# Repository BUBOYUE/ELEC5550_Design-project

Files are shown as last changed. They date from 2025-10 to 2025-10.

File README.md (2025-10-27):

## Version Information

- **Version:** 3.1 (Final Release)
- **Date:** 2025-10-27
- **Editor:** Boyue BU
- **Description:**
  - Fixed unstable recognition issues for different mouse types.
  - Added support for recognizing different signaling variants of mouse/keyboard (Report/Boot protocol, Report ID handling).
  - Mouse, keyboard, and U‑Disk functionalities are now complete.
  - Adjusted documentation to reflect the new HID compatibility improvements.
  - Completed the final version of the project (software, hardware, and documentation updated).
  - Added compatibility note for **ESP32-S3 DevKitC V1**, allowing firmware testing without the custom PCB.
  - Improved **Host/Device** dual communication protocol and FEC verification mechanism.
  - Updated **README.md** with library linking instructions and board compatibility notes.
  - Added **BSD 3-Clause License** for attribution-based redistribution.
  - Expanded **References** section with official ESP-IDF and TinyUSB sources.
  - Adjusted folder structure for correct GitHub rendering.
  - Enhanced TinyUSB HID/MSC framework and debugging interfaces.

# ELEC5550 Design Project – Laser-Based USB Communication System

This repository contains the complete design files for the **ELEC5550 Design Project** at the **University of Western Australia (UWA)**.  
The goal of this project is to develop a **dual ESP32-S3 optical communication bridge** that enables transparent data transfer between a **PC** and **USB devices** (keyboard, mouse, or mass storage) through a **laser-based optical link**.

---

## 📁 Project Structure

```
ELEC5550_Design-project/
│
├── docs/                         # datasheets,figures
│
├── hardware/                     # Hardware design files
│   ├── schematics/               # Circuit schematics (KiCad / Altium)
│   ├── pcb/                      # PCB layout and Gerber files
│   └── sim/                      # Simulation on LTspice
│
├── software/                     # Firmware source code for ESP32-S3 boards
│   ├── esp32_a_host/             # Host-side firmware (USB Host + UART TX)
│   ├── esp32_b_device/           # Device-side firmware (UART RX + USB Device)
│   ├── esp32s3_usb_passthrough/  # Combined HID + MSC passthrough final demo
│   └── libraries/                # Local Arduino libraries (CRC, UART, FEC, etc.)
│
├── tools/                        # Utility scripts or helper tools
│
└── README.md 
```

---

## 🧩 Hardware Compatibility

This project is designed for the **ESP32-S3 WROOM N16R8** module used on the custom PCB.  
If you do not have access to the fabricated PCB, the firmware can still be tested using an **ESP32-S3 DevKitC V1** board.  
Simply connect the UART interface between two boards according to the schematic, and the program will run with equivalent functionality.

---

## ⚙️ Setup Guide

### 1. Clone the Repository
```bash
git clone https://github.com/BUBOYUE/ELEC5550_Design-project.git
```

### 2. Link the Local Libraries
To ensure the Arduino IDE can locate the custom libraries used in this project, create symbolic links from the project’s `libraries` folder to your Arduino library path.

**Mac/Linux:**
```bash
ln -s <path_to_project>/software/libraries ~/Documents/Arduino/libraries/ELEC5550_LIBS
```

**Windows (PowerShell):**
```powershell
New-Item -ItemType SymbolicLink -Path "$env:USERPROFILE\Documents\Arduino\libraries\ELEC5550_LIBS" -Target "<path_to_project>\software\libraries"
```

### 3. Open and Flash
1. Open `esp32_a_host.ino` or `esp32_b_device.ino` using Arduino IDE.  
2. Select **Board:** `ESP32S3 Dev Module`.  
3. Set **Upload Speed:** `460800`.  
4. Enable **USB CDC On Boot** if available.  
5. Connect the board and upload.

---

## 💡 Project Overview

- **Architecture:** Dual ESP32-S3 optical bridge  
- **Communication Link:** UART or laser-based optical channel  
- **Supported Protocols:** HID (mouse/keyboard) + MSC (USB mass storage)  
- **Error Handling:** CRC-16 + Reed–Solomon FEC  
- **Operating Voltage:** 5V / 1A (from PC or power bank)

The host board (ESP32-A) acts as a USB Host, while the device board (ESP32-B) emulates a USB peripheral, enabling transparent USB data transmission over light.

---

## 🧠 Contributors
- **Boyue BU** – Software (Host-side, USB HID/MSC RTOS structure)
- **Elyney OU** – Software (Device-side, TinyUSB HID/MSC logic)
- **Kunze CHEN** – Software (UART Communication Protocol, Error Correction)
- **Zhanjun XU** – Hardware (Laser Driver Design & PCB design)
- **Zhe WANG** – Hardware (Receiver Design & PCB design)
- **Bowen LIU** – Hardware (Receiver Design & PCB design)

---

## 🧩 References
- [ESP-IDF TinyUSB Examples](https://github.com/espressif/esp-idf/tree/master/examples/peripherals/usb)
- [Arduino-ESP32 USBMSC Example](https://github.com/espressif/arduino-esp32/blob/master/libraries/USB/examples/USBMSC/USBMSC.ino)
- [TinyUSB Library](https://github.com/hathach/tinyusb)
- [Reed–Solomon C++ Implementation (mersinvald)](https://github.com/mersinvald/Reed-Solomon/blob/master/include/rs.hpp)
- [CRC Algorithms Reference (Boost.CRC library, C++)](https://www.boost.org/doc/libs/release/libs/crc/crc.html)
- [ESP-IDF USB Host HID Example](https://github.com/espressif/esp-idf/tree/master/examples/peripherals/usb/host/hid)
- [ESP-IDF USB Host MSC Example](https://github.com/espressif/esp-idf/tree/master/examples/peripherals/usb/host/msc)
- [HID Report Parser](https://github.com/pasztorpisti/hid-report-parser)
---

## 📜 License
This project is licensed under the [BSD 3-Clause License](./LICENSE).  
© 2025 ELEC5550 Optical Communication Team, University of Western Australia.  
Redistribution is permitted with acknowledgment of the original authors.

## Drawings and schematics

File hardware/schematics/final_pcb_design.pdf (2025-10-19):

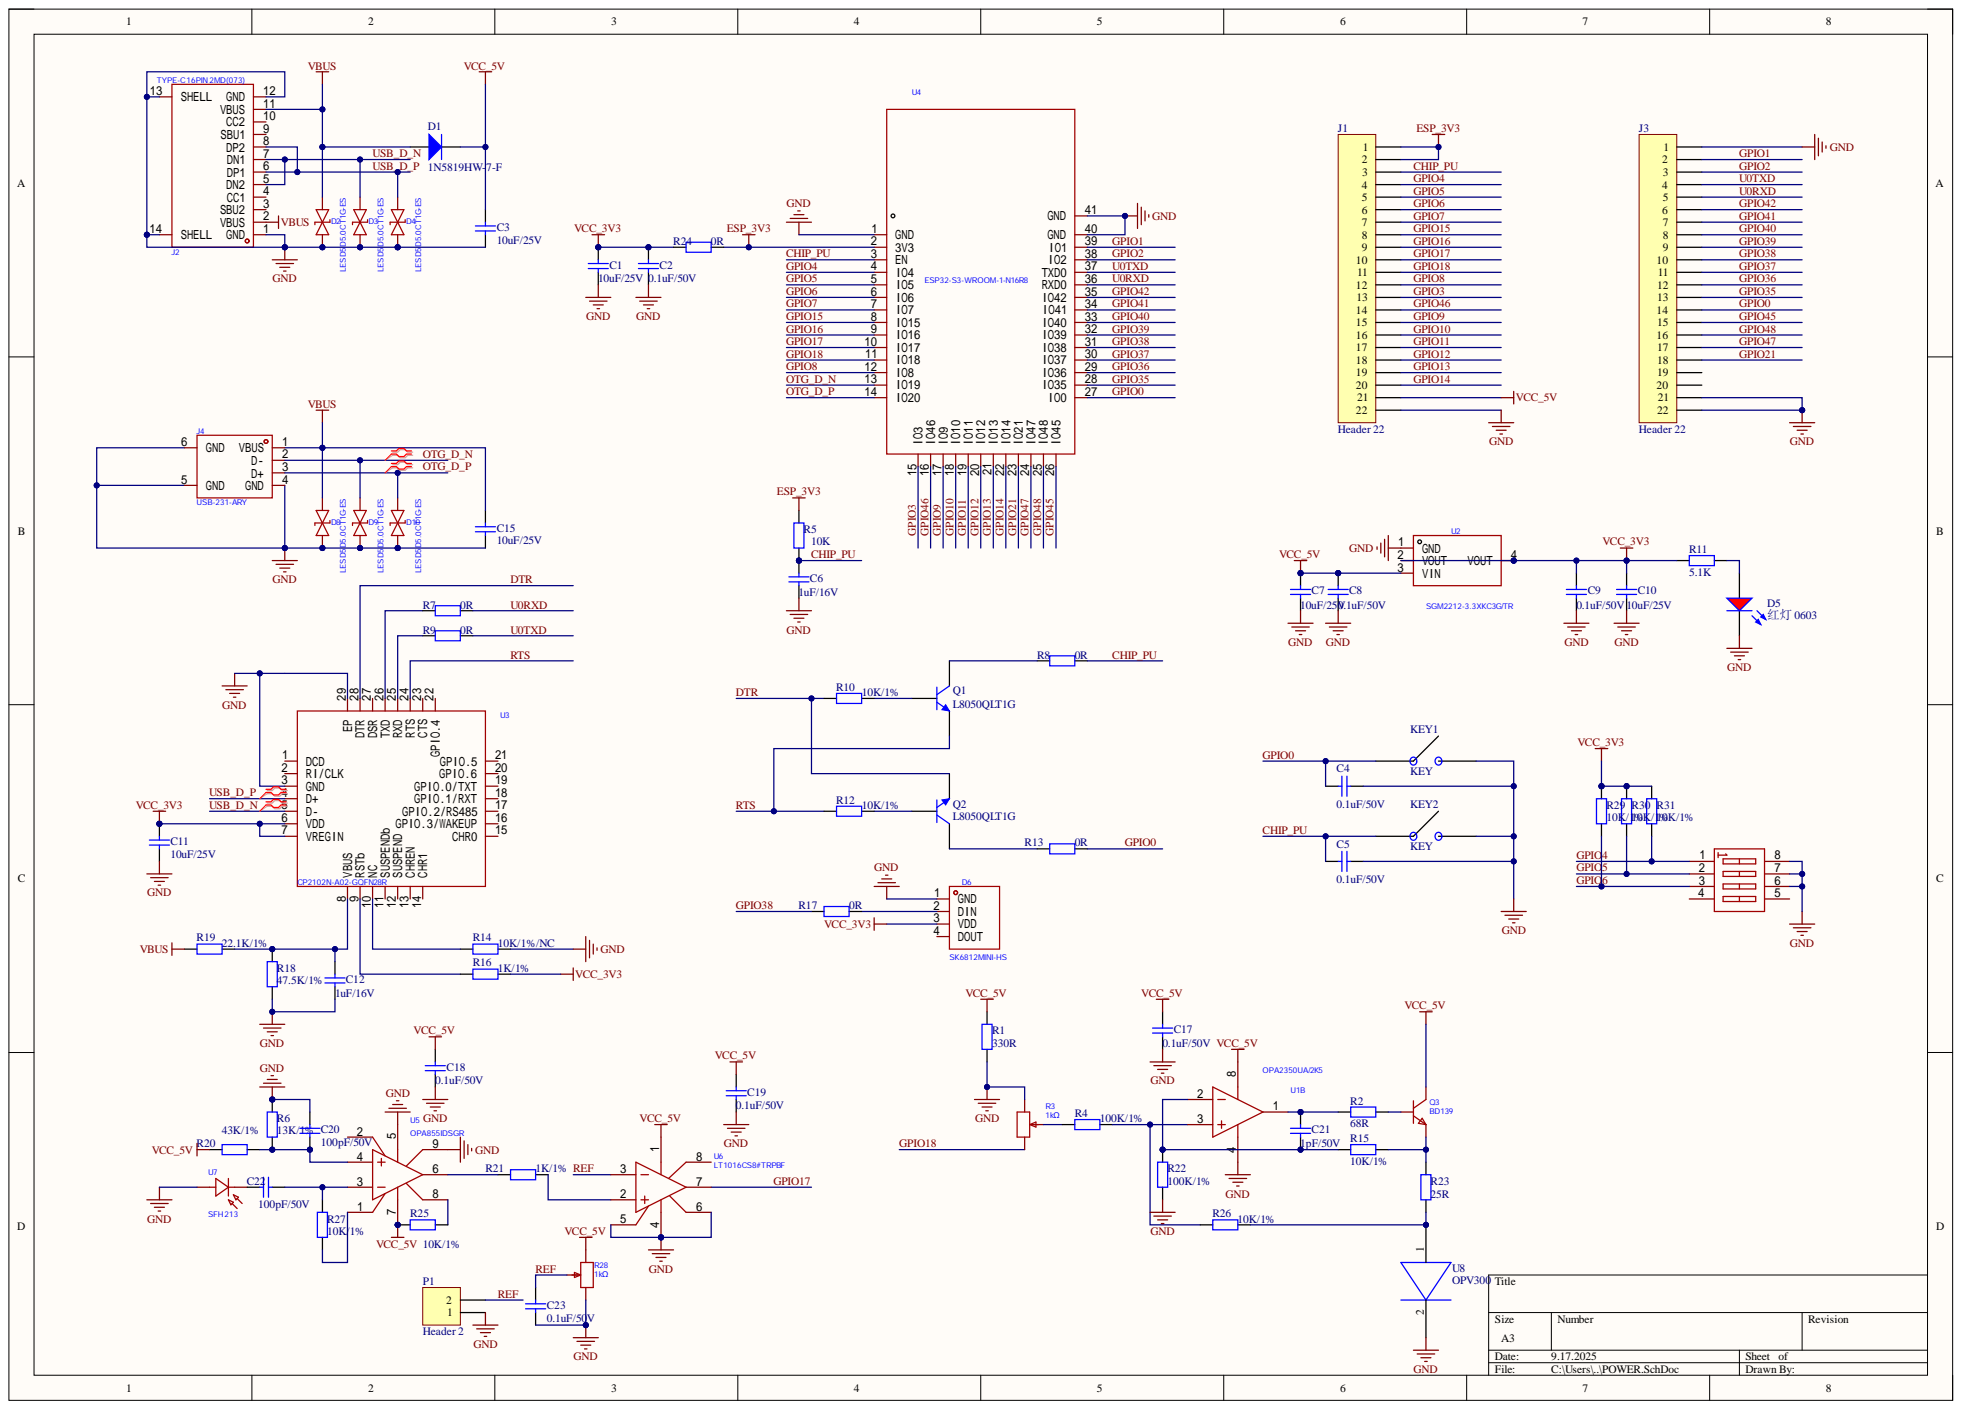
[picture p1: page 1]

OTG_D_N
OTG_D_P

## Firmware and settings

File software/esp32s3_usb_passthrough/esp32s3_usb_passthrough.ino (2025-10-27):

/*
 * Project: ELEC5550 Laser USB Passthrough (ESP32‑S3)
 * File:    esp32s3_usb_passthrough.ino
 * Authors : UWA ELEC5550 Team 13 (merged by Boyue BU)
 * Date:    2025-10-15
 * 
 * Summary:
 *   Unified sketch that lets one ESP32‑S3 board act as a USB Host (HID + MSC)
 *   and transparently bridge traffic to a peer ESP32‑S3 over UART using a
 *   framed protocol with CRC and optional FEC (Reed–Solomon). The peer may act
 *   as a USB Device endpoint (HID/MSC). Mode selection is done via GPIO5.
 *
 * Context:
 *   University of Western Australia (UWA) – ELEC5550 Design Project, Group 13.
 *   This file consolidates the previously separate HID and MSC passthrough
 *   sketches and adds UART framing, task scheduling, and logging for a laser
 *   data link.
 *
 * Key Features:
 *   - TinyUSB Host: HID (keyboard/mouse) + MSC (U‑Disk) handling on S3‑A
 *   - UART framing: Type/Len/Payload + CRC, optional RS FEC (payload ≤ 224 B)
 *   - FreeRTOS tasks: USB events, MSC app queue, UART RX/TX, HID callbacks
 *   - Zero‑block optimization for MSC reads (U_EMPTY), write acknowledgement
 *   - Dual‑mode: Host/Device decided by GPIO5 (HIGH=Host, LOW=Device)
 *
 * Build/Run Notes:
 *   - Platform: Arduino‑ESP32 for ESP32‑S3
 *   - Serial monitor: 460800 bps (logging and diagnostics)
 *   - Power/role: Set board role with the on‑board switch tied to GPIO5
 *
 * References:
 *   - ESP‑IDF examples: HID Host (hid_host) and MSC Host (msc_host)
 *   - TinyUSB stack and ESP32‑S3 USB Host driver
 *
 * Disclaimer:
 *   Educational code produced by UWA student team; provided "as is" without any
 *   warranty. Review licensing before redistribution.
 */


#include <Arduino.h>
#include <stdio.h>
#include <string.h>
#include <wchar.h>
#include <inttypes.h>
#include <sys/stat.h>
#include <dirent.h>
#include <errno.h>

#include "freertos/FreeRTOS.h"
#include "freertos/task.h"
#include "freertos/queue.h"

#include "esp_err.h"
#include "esp_log.h"
#include "esp_timer.h"

#include "driver/gpio.h"
#include "usb/usb_host.h"

#include "hid_host.h"
#include "hid_usage_keyboard.h"
#include "hid_usage_mouse.h"

#include "msc_host.h"
#include "msc_host_vfs.h"

#include "uart.h"   // Provides: uart2_init(), send_frame(...)
#include "usb.h"    // Optional: for future USB HID device forwarding

#include "device.h" // Declares device_usb_init / device_mouse_and_keyboard / Close_Ustick etc.

#include "hid_report_parser.h"

/**
 * @brief HID Protocol string names
 */
static const char *hid_proto_name_str[] = {"NONE", "KEYBOARD", "MOUSE"};

/**
 * @brief Key event
 */
typedef struct {
  enum key_state { KEY_STATE_PRESSED = 0x00, KEY_STATE_RELEASED = 0x01 } state;
  uint8_t modifier;
  uint8_t key_code;
} key_event_t;

typedef struct {
  hid::SelectiveInputReportParser parser;
  hid::MouseConfig cfg;
  hid::BoolVector buttons;
  hid::Int32Vector axes;
  bool inited;
} mouse_parser_ctx_t;

static mouse_parser_ctx_t g_mouse_ctx = {};

static void mouse_parser_reset(void) {
  g_mouse_ctx.parser.Reset();
  g_mouse_ctx.inited = false;
}

static void mouse_parser_init(hid_host_device_handle_t hid_device_handle) {
  size_t desc_len = 0;
  uint8_t* desc_ptr = hid_host_get_report_descriptor(hid_device_handle, &desc_len);
  if (!desc_ptr || desc_len == 0) {
    Serial.printf("[HID][Mouse] get report descriptor failed (len=%u)\n", (unsigned)desc_len);
    mouse_parser_reset();
    return;
  }

  hid::Collection* root = g_mouse_ctx.cfg.Init(&g_mouse_ctx.buttons, &g_mouse_ctx.axes, false);
  int r = g_mouse_ctx.parser.Init(root, (const void*)desc_ptr, desc_len);
  if (r != hid::ERR_SUCCESS) {
    root = g_mouse_ctx.cfg.Init(&g_mouse_ctx.buttons, &g_mouse_ctx.axes, true);
    r = g_mouse_ctx.parser.Init(root, (const void*)desc_ptr, desc_len);
  }

  if (r == hid::ERR_SUCCESS) {
    g_mouse_ctx.inited = true;
    Serial.printf("[HID][Mouse] parser ready (desc_len=%u)\n", (unsigned)desc_len);
  } else {
    Serial.printf("[HID][Mouse] parser init failed: %s (%d)\n", hid::str_error(r, "ERR"), r);
    mouse_parser_reset();
  }
}


static const char *TAG = "example";

#ifndef MNT_PATH
#define MNT_PATH "/usb"
#endif
#ifndef BUFFER_SIZE
#define BUFFER_SIZE (4 * 1024)
#endif
#ifndef APP_QUIT_PIN
#define APP_QUIT_PIN GPIO_NUM_0
#endif
// IMPORTANT NOTE
// MSC Class Driver is not fully support connecting devices through external Hub.
// TODO: Remove this line after MSC Class Driver will support it
static bool dev_present = false;

static uint32_t g_sector_size = 512;                 // Updated from device info
static msc_host_device_handle_t g_msc_dev = NULL;    // Current MSC device handle
static const uint8_t CHUNK_DATA_MAX = 224;           // Max data length per frame chunk (changed from 240 to 224)

/**
 * @brief Application Queue and its messages ID
 */
static QueueHandle_t app_queue;

typedef enum {
    APP_QUIT = 0,             // Explicitly define values
    APP_DEVICE_CONNECTED,
    APP_DEVICE_DISCONNECTED,
    APP_COMMAND,
} app_event_id_t;

typedef struct {
    app_event_id_t id;
    union {
        uint8_t new_dev_address;
        struct {                   // For UART command forwarding
            uint8_t type;          // Frame type (MsgType)
            uint8_t data[256];     // Payload
            uint8_t len;           // Payload length
        } cmd;
    } data;
} app_message_t;

// PC sends "raw type + raw payload" to this board via UART:
//   - Mouse:  TYPE = 0x01, followed by 3 bytes [dx, dy, btn]
//   - Keyboard: TYPE = 0x02, followed by 8 bytes [modifier, key1..key6, reserved]
// This board packs this raw payload using send_frame(type, payload, len) (adds STX/CRC) and sends downstream.

/*
 * SPDX-FileCopyrightText: 2022-2023 Espressif Systems (Shanghai) CO LTD
 *
 * SPDX-License-Identifier: Unlicense OR CC0-1.0
 */

/* GPIO Pin number for quit from example logic */
#define APP_QUIT_PIN                GPIO_NUM_0

QueueHandle_t hid_host_event_queue;
bool user_shutdown = false;

/**
 * @brief HID Host event
 *
 * This event is used for delivering the HID Host event from callback to a task.
 */
typedef struct {
  hid_host_device_handle_t hid_device_handle;
  hid_host_driver_event_t event;
  void *arg;
} hid_host_event_queue_t;


/* Main char symbol for ENTER key */
#define KEYBOARD_ENTER_MAIN_CHAR '\r'
/* When set to 1 pressing ENTER will be extending with LineFeed during serial
 * debug output */
#define KEYBOARD_ENTER_LF_EXTEND 1

/**
 * @brief Scancode to ascii table
 */
const uint8_t keycode2ascii[57][2] = {
    {0, 0},     /* HID_KEY_NO_PRESS        */
    {0, 0},     /* HID_KEY_ROLLOVER        */
    {0, 0},     /* HID_KEY_POST_FAIL       */
    {0, 0},     /* HID_KEY_ERROR_UNDEFINED */
    {'a', 'A'}, /* HID_KEY_A               */
    {'b', 'B'}, /* HID_KEY_B               */
    {'c', 'C'}, /* HID_KEY_C               */
    {'d', 'D'}, /* HID_KEY_D               */
    {'e', 'E'}, /* HID_KEY_E               */
    {'f', 'F'}, /* HID_KEY_F               */
    {'g', 'G'}, /* HID_KEY_G               */
    {'h', 'H'}, /* HID_KEY_H               */
    {'i', 'I'}, /* HID_KEY_I               */
    {'j', 'J'}, /* HID_KEY_J               */
    {'k', 'K'}, /* HID_KEY_K               */
    {'l', 'L'}, /* HID_KEY_L               */
    {'m', 'M'}, /* HID_KEY_M               */
    {'n', 'N'}, /* HID_KEY_N               */
    {'o', 'O'}, /* HID_KEY_O               */
    {'p', 'P'}, /* HID_KEY_P               */
    {'q', 'Q'}, /* HID_KEY_Q               */
    {'r', 'R'}, /* HID_KEY_R               */
    {'s', 'S'}, /* HID_KEY_S               */
    {'t', 'T'}, /* HID_KEY_T               */
    {'u', 'U'}, /* HID_KEY_U               */
    {'v', 'V'}, /* HID_KEY_V               */
    {'w', 'W'}, /* HID_KEY_W               */
    {'x', 'X'}, /* HID_KEY_X               */
    {'y', 'Y'}, /* HID_KEY_Y               */
    {'z', 'Z'}, /* HID_KEY_Z               */
    {'1', '!'}, /* HID_KEY_1               */
    {'2', '@'}, /* HID_KEY_2               */
    {'3', '#'}, /* HID_KEY_3               */
    {'4', '$'}, /* HID_KEY_4               */
    {'5', '%'}, /* HID_KEY_5               */
    {'6', '^'}, /* HID_KEY_6               */
    {'7', '&'}, /* HID_KEY_7               */
    {'8', '*'}, /* HID_KEY_8               */
    {'9', '('}, /* HID_KEY_9               */
    {'0', ')'}, /* HID_KEY_0               */
    {KEYBOARD_ENTER_MAIN_CHAR, KEYBOARD_ENTER_MAIN_CHAR}, /* HID_KEY_ENTER */
    {0, 0},      /* HID_KEY_ESC             */
    {'\b', 0},   /* HID_KEY_DEL             */
    {0, 0},      /* HID_KEY_TAB             */
    {' ', ' '},  /* HID_KEY_SPACE           */
    {'-', '_'},  /* HID_KEY_MINUS           */
    {'=', '+'},  /* HID_KEY_EQUAL           */
    {'[', '{'},  /* HID_KEY_OPEN_BRACKET    */
    {']', '}'},  /* HID_KEY_CLOSE_BRACKET   */
    {'\\', '|'}, /* HID_KEY_BACK_SLASH      */
    {'\\', '|'},
    /* HID_KEY_SHARP           */ // HOTFIX: for NonUS Keyboards repeat
                                  // HID_KEY_BACK_SLASH
    {';', ':'},                   /* HID_KEY_COLON           */
    {'\'', '"'},                  /* HID_KEY_QUOTE           */
    {'`', '~'},                   /* HID_KEY_TILDE           */
    {',', '<'},                   /* HID_KEY_LESS            */
    {'.', '>'},                   /* HID_KEY_GREATER         */
    {'/', '?'}                    /* HID_KEY_SLASH           */
};

/**
 * @brief Makes new line depending on report output protocol type
 *
 * @param[in] proto Current protocol to output
 */
static void hid_print_new_device_report_header(hid_protocol_t proto) {
  static hid_protocol_t prev_proto_output = HID_PROTOCOL_MAX;

  if (prev_proto_output != proto) {
    prev_proto_output = proto;
    printf("\r\n");
    if (proto == HID_PROTOCOL_MOUSE) {
      printf("Mouse\r\n");
    } else if (proto == HID_PROTOCOL_KEYBOARD) {
      printf("Keyboard\r\n");
    } else {
      printf("Generic\r\n");
    }
    fflush(stdout);
  }
}

/**
 * @brief HID Keyboard modifier verification for capitalization application
 * (right or left shift)
 *
 * @param[in] modifier
 * @return true  Modifier was pressed (left or right shift)
 * @return false Modifier was not pressed (left or right shift)
 *
 */
static inline bool hid_keyboard_is_modifier_shift(uint8_t modifier) {
  if (((modifier & HID_LEFT_SHIFT) == HID_LEFT_SHIFT) ||
      ((modifier & HID_RIGHT_SHIFT) == HID_RIGHT_SHIFT)) {
    return true;
  }
  return false;
}

/**
 * @brief HID Keyboard get char symbol from key code
 *
 * @param[in] modifier  Keyboard modifier data
 * @param[in] key_code  Keyboard key code
 * @param[in] key_char  Pointer to key char data
 *
 * @return true  Key scancode converted successfully
 * @return false Key scancode unknown
 */
static inline bool hid_keyboard_get_char(uint8_t modifier, uint8_t key_code,
                                         unsigned char *key_char) {
  uint8_t mod = (hid_keyboard_is_modifier_shift(modifier)) ? 1 : 0;

  if ((key_code >= HID_KEY_A) && (key_code <= HID_KEY_SLASH)) {
    *key_char = keycode2ascii[key_code][mod];
  } else {
    // All other key pressed
    return false;
  }

  return true;
}

/**
 * @brief HID Keyboard print char symbol
 *
 * @param[in] key_char  Keyboard char to stdout
 */
static inline void hid_keyboard_print_char(unsigned int key_char) {
  if (!!key_char) {
    putchar(key_char);
#if (KEYBOARD_ENTER_LF_EXTEND)
    if (KEYBOARD_ENTER_MAIN_CHAR == key_char) {
      putchar('\n');
    }
#endif // KEYBOARD_ENTER_LF_EXTEND
    fflush(stdout);
  }
}

/**
 * @brief Key Event. Key event with the key code, state and modifier.
 *
 * @param[in] key_event Pointer to Key Event structure
 *
 */
static void key_event_callback(key_event_t *key_event) {
  unsigned char key_char;

  hid_print_new_device_report_header(HID_PROTOCOL_KEYBOARD);

  if (key_event->KEY_STATE_PRESSED == key_event->state) {
    if (hid_keyboard_get_char(key_event->modifier, key_event->key_code,
                              &key_char)) {

      hid_keyboard_print_char(key_char);
    }
  }
}

/**
 * @brief Key buffer scan code search.
 *
 * @param[in] src       Pointer to source buffer where to search
 * @param[in] key       Key scancode to search
 * @param[in] length    Size of the source buffer
 */
static inline bool key_found(const uint8_t *const src, uint8_t key,
                             unsigned int length) {
  for (unsigned int i = 0; i < length; i++) {
    if (src[i] == key) {
      return true;
    }
  }
  return false;
}

/**
 * @brief USB HID Host Keyboard Interface report callback handler
 *
 * @param[in] data    Pointer to input report data buffer
 * @param[in] length  Length of input report data buffer
 */
static void hid_host_keyboard_report_callback(const uint8_t *const data,
                                              const int length) {
  hid_keyboard_input_report_boot_t *kb_report =
      (hid_keyboard_input_report_boot_t *)data;

  if (length < sizeof(hid_keyboard_input_report_boot_t)) {
    return;
  }

  // DEBUG: one-line dump of keyboard report
  printf("[DBG][KB] size=%d hex:", length);
  for (int i = 0; i < length; ++i) printf(" %02X", data[i]);
  printf("\r\n");
  fflush(stdout);
  
  // ---- Send raw Boot keyboard snapshot via UART (type=0x02) ----
  // Payload layout (8 bytes): [0]=modifier, [1]=reserved(0), [2..7]=key[6]
  uint8_t kb_payload[8];
  kb_payload[0] = kb_report->modifier.val; // modifiers (Ctrl/Shift/Alt/GUI)
  kb_payload[1] = 0x00;                    // reserved
  memcpy(&kb_payload[2], kb_report->key, 6);
  send_frame(0x02, kb_payload, 8);

  static uint8_t prev_keys[HID_KEYBOARD_KEY_MAX] = {0};
  key_event_t key_event;

  for (int i = 0; i < HID_KEYBOARD_KEY_MAX; i++) {

    // key has been released verification
    if (prev_keys[i] > HID_KEY_ERROR_UNDEFINED &&
        !key_found(kb_report->key, prev_keys[i], HID_KEYBOARD_KEY_MAX)) {
      key_event.key_code = prev_keys[i];
      key_event.modifier = 0;
      key_event.state = key_event.KEY_STATE_RELEASED;
      key_event_callback(&key_event);
    }

    // key has been pressed verification
    if (kb_report->key[i] > HID_KEY_ERROR_UNDEFINED &&
        !key_found(prev_keys, kb_report->key[i], HID_KEYBOARD_KEY_MAX)) {
      key_event.key_code = kb_report->key[i];
      key_event.modifier = kb_report->modifier.val;
      key_event.state = key_event.KEY_STATE_PRESSED;
      key_event_callback(&key_event);
    }
  }

  memcpy(prev_keys, &kb_report->key, HID_KEYBOARD_KEY_MAX);
}

/**
 * @brief USB HID Host Mouse Interface report callback handler
 *
 * @param[in] data    Pointer to input report data buffer
 * @param[in] length  Length of input report data buffer
 */
static void hid_host_mouse_report_callback(const uint8_t *const data,
                                           const int length){
  // Prefer to parse using Report Descriptor first
  bool sent = false;
  if (g_mouse_ctx.inited && data && length > 0) {
    int pr = g_mouse_ctx.parser.Parse(data, (size_t)length);
    if (pr == hid::ERR_SUCCESS) {
      // Collect buttons (up to 5: left, right, middle, back, forward)
      uint8_t buttons = 0;
      buttons |= (g_mouse_ctx.buttons[hid::MouseConfig::BTN_LEFT]   ? 0x01 : 0);
      buttons |= (g_mouse_ctx.buttons[hid::MouseConfig::BTN_RIGHT]  ? 0x02 : 0);
      buttons |= (g_mouse_ctx.buttons[hid::MouseConfig::BTN_MIDDLE] ? 0x04 : 0);
      buttons |= (g_mouse_ctx.buttons[hid::MouseConfig::BTN_BACK]   ? 0x08 : 0);
      buttons |= (g_mouse_ctx.buttons[hid::MouseConfig::BTN_FORWARD]? 0x10 : 0);

      // Collect relative axes: X/Y and wheel
      int32_t dx32 = g_mouse_ctx.axes[hid::MouseConfig::X];
      int32_t dy32 = g_mouse_ctx.axes[hid::MouseConfig::Y];
      int32_t wh32 = g_mouse_ctx.axes[hid::MouseConfig::V_SCROLL];

      // Saturate to int8
      auto sat8 = [](int32_t v)->int8_t {
        if (v > 127) return 127;
        if (v < -128) return -128;
        return (int8_t)v;
      };
      int8_t dx = sat8(dx32);
      int8_t dy = sat8(dy32);
      int8_t wheel = sat8(wh32);

      // Send 4-byte payload: [buttons, dx, dy, wheel]
      uint8_t payload[4];
      payload[0] = buttons;
      payload[1] = (uint8_t)dx;
      payload[2] = (uint8_t)dy;
      payload[3] = (uint8_t)wheel;
      send_frame(0x01, payload, 4);
      sent = true;

      // Debug output
      hid_print_new_device_report_header(HID_PROTOCOL_MOUSE);
      printf("X:%06d\tY:%06d\tW:%4d\t|%c|%c|%c|\r \n",
             (int)dx, (int)dy, (int)wheel,
             (buttons & 0x01) ? 'o' : ' ',
             (buttons & 0x02) ? 'o' : ' ',
             (buttons & 0x04) ? 'o' : ' ');
      fflush(stdout);
    }
    // pr==ERR_NOTHING_CHANGED 或错误：回退到启发式
  }

  if (sent) return;

  // Fallback: original heuristic processing, compatible with unparsed cases
  // DEBUG: dump raw mouse report as signed decimal (int8)
  printf("[DBG][MOUSE] size=%d s8:", length);
  for (int i = 0; i < length; ++i) printf(" %4d", (int)((int8_t)data[i]));
  printf("\r\n");
  fflush(stdout);
  // Auto-adapt Boot/Report common layouts; see above three formats
  const uint8_t *p = data;
  int remaining = length;
  if (remaining < 3) return;

  // Simple heuristic: if byte 0 doesn't look like button mask but byte 1 does, assume byte 0 is Report ID
  bool has_report_id = false;
  if ((p[0] & 0xF8) && remaining >= 5 && (p[1] & 0xF8) == 0) {
    has_report_id = true;
    p++; remaining--;
  }

  uint8_t buttons = p[0];
  int8_t dx = (remaining >= 2) ? (int8_t)p[1] : 0;
  // ----- Robust Y: treat p[3] as signed high byte, then scale by 8 with signed rounding -----
  int16_t dy16 = 0;
  if (remaining >= 4) {
    // Little-endian 16-bit: low=p[2], high=p[3] (high is signed)
    int8_t dy_hi = (int8_t)p[3];
    uint8_t dy_lo = (remaining >= 3) ? p[2] : 0;
    dy16 = (int16_t)(((int16_t)dy_hi << 8) | (uint16_t)dy_lo);
  } else {
    // Fallback to 8-bit
    dy16 = (int16_t)((remaining >= 3) ? (int8_t)p[2] : 0);
  }
  // Signed rounding division by 8 to match desired sensitivity
  int dy_scaled = (dy16 >= 0) ? (((int)dy16 + 4) / 8) : (((int)dy16 - 4) / 8);
  if (dy_scaled > 127) dy_scaled = 127;
  if (dy_scaled < -128) dy_scaled = -128;
  int8_t dy = (int8_t)dy_scaled;
  // Debug print for combined Y values
  printf("[DBG][MOUSE] dy_lo=0x%02X dy_hi=0x%02X dy16=%d dy=%d\r\n", (remaining>=3?p[2]:0), (remaining>=4?p[3]:0), (int)dy16, (int)dy);
  fflush(stdout);
  int8_t wheel = 0;
  int8_t wheel_h = 0; // optional horizontal wheel

  if (remaining == 6) {
    // Observed format from your logs:
    // [0]=buttons, [1]=dx, [2]=dy, [3]=horiz(wheel H?), [4]=wheel V, [5]=reserved
    wheel_h = (int8_t)p[3];
    wheel   = (int8_t)p[4];
  } else if (remaining >= 4) {
    // Default common format: [buttons][dx][dy][wheel]
    wheel = (int8_t)p[3];
  }

  // Pack useful 4-byte payload: [buttons(2:middle 1:right 0:left), dx, dy, wheel]
  uint8_t payload[4];
  payload[0] = buttons;
  payload[1] = (uint8_t)dx;
  payload[2] = (uint8_t)dy;
  payload[3] = (uint8_t)wheel;
  send_frame(0x01, payload, 4);

  hid_print_new_device_report_header(HID_PROTOCOL_MOUSE);
  printf("X:%06d\tY:%06d\t", dx, dy);
  if (remaining >= 4) printf("W:%4d\t", (int)wheel);
  printf("|%c|%c|%c|%s\r \n",
         (buttons & 0x01) ? 'o' : ' ',
         (buttons & 0x02) ? 'o' : ' ',
         (buttons & 0x04) ? 'o' : ' ',
         has_report_id ? "RID" : "");
  fflush(stdout);
}

/**
 * @brief USB HID Host Generic Interface report callback handler
 *
 * 'generic' means anything else than mouse or keyboard
 *
 * @param[in] data    Pointer to input report data buffer
 * @param[in] length  Length of input report data buffer
 */
static void hid_host_generic_report_callback(const uint8_t *const data,
                                             const int length) {
  hid_print_new_device_report_header(HID_PROTOCOL_NONE);
  for (int i = 0; i < length; i++) {
    printf("%02X", data[i]);
  }
  putchar('\r');
  putchar('\n');
  fflush(stdout);
}
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
void loop() {
  if (g_run_host) {
    // Host/passthrough mode: all work runs in threads, keep loop() empty to avoid interference
    // Yield CPU time appropriately:
    vTaskDelay(pdMS_TO_TICKS(10));
    return;
  }

  // Device mode: maintain original logic
  // Not ready or mode is NONE -> reinitialize
  if (!g_usb_ready || g_Mode == NONE) {
    if (!g_device_inited || !g_usb_ready) {
      device_usb_init();
      g_device_inited = true;
    }
    vTaskDelay(pdMS_TO_TICKS(5));
    return;
  }

  // HID mode: UART -> HID forwarding
  if (g_Mode == HID) {
    device_mouse_and_keyboard();
    // Function internally blocks/polls; no additional delay needed here
  }
  // MSC mode: PC drives through callbacks, no active intervention needed; only monitor if reinitialization is needed
  else if (g_Mode == USTICK) {
    if (check_reinit_needed()) {
      Close_Ustick();   // Trigger device-side cleanup, next iteration will go to initialization branch
    }
    vTaskDelay(pdMS_TO_TICKS(1));
  }
}

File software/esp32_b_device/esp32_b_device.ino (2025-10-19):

/*
 * Project: ELEC5550 Laser USB Passthrough (ESP32‑S3)
 * File:    esp32_b_device.ino
 *
 * Author:  Elyney OU
 * Institution: University of Western Australia (UWA)
 * Course:  ELEC5550 Design Project – Group 13
 *
 * Summary:
 *   This sketch implements the Device‑side logic of the optical USB bridging system.
 *   The ESP32‑S3 acts as a USB Device endpoint, supporting both HID (keyboard/mouse)
 *   and MSC (USB mass storage) passthrough modes. It interfaces with the Host‑side
 *   board through a custom UART frame protocol featuring CRC and optional FEC for
 *   data integrity.
 *
 * Functional Overview:
 *   - Initializes UART2 for bidirectional data exchange.
 *   - Enumerates as either HID or MSC device using TinyUSB stack.
 *   - For HID mode: forwards UART input reports to the PC in real time.
 *   - For MSC mode: coordinates SCSI command handling and re‑initialization.
 *
 * Reference:
 *   Based on and adapted from ESP‑IDF examples:
 *     - HID Device example: examples/peripherals/usb/device/hid
 *     - MSC Device example: examples/peripherals/usb/device/msc
 *   Original extensions include optical‑link data framing and automatic re‑init logic.
 *
 * Build Notes:
 *   - Platform: Arduino‑ESP32 (ESP32‑S3)
 *   - Baud rate: 460800 bps (recommended)
 *   - Switch configuration: left = A‑end, right = B‑end
 *
 * Disclaimer:
 *   Developed by UWA students team for academic use. Provided as‑is without warranty.
 */

#include "device.h"
#include "uart.h"
#include <Arduino.h>

void setup() {
  Serial.begin(921600/2);                         // Serial port initialization
  uart2_init();                                   // UART initialization
  Serial.println("Uart done");
  device_usb_init();                              // Enumerate as HID mouse/keyboard or USB storage
  Serial.println("USB initialization done");
}

void loop() {
  // if (Serial2.available()) {
  //   Serial.write(Serial2.read());}
  
  // Not initialized or exited initialization, go initialize
  if (!g_usb_ready || g_Mode == NONE) {
    device_usb_init();
    return; // Let next loop iteration judge again
  }
  
  // HID mode continuous loop until exit (forced exit/switch to USB storage)
  if (g_Mode == HID){
  device_mouse_and_keyboard();                    // UART → HID forwarding
  }

  // MSC mode does nothing, PC will call callback functions
  else if (g_Mode == USTICK){
    
    // Do nothing but detect if USB stick removed
    if (check_reinit_needed()) {
      Close_Ustick();
    }
  }

}

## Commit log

2025-08-16 更新说明：实现了ab板间通信解码。uart初始化未统一，是单独初始化。鼠标控制未实现。
2025-08-16 updata uart2_init
2025-08-26 feat: 新增 uart2.h/.cpp，带 TYPE 的帧协议（鼠标+键盘）
2025-08-26 删除uart2库，合并uart和uart2功能到uart库中
2025-08-30 Add esp32_a_host.ino function of Keyboard&Mouse for Testing
2025-09-05 host update: full mouse function and send_frame to device-end
2025-09-06 现在可以用a板传输到b板控制鼠标，已经使用改动后的uart初始化设置，鼠标控制实现。
2025-09-06 更新了鼠标device阅读格式，匹配host端发送格式
2025-09-06 device端鼠标+键盘功能完全跑通，鼠标移动+全键，键盘全键可用。完美！
2025-09-25 Add MSC host test files esp32 host code
2025-09-29 uart_ack
    有ack版本的uart
2025-10-04 uart with FEC
2025-10-04 uart.cpp with print error
2025-10-06 update uart.h MsgType
2025-10-10 MSC device-end done
2025-10-10 Version 2.0: merged dual main logic (HID+MSC) with GPIO5 mode selection; tested successfully on ESP32-S3 DevKitC
2025-10-19 Version 3.0 Final Release: Full system, documentation, and license update
    [Air780E.PcbLib, Laser.PrjPcb, LaserPCB.PcbLib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]
2025-10-27 Version 3.1: Fixed unstable issues for different mouse types
    [esp32s3_usb_passthrough.ino]
